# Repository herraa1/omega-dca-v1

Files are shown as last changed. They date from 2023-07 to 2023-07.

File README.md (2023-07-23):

# Omega DC Adapter (DCA) v1

DC adapter for the [Omega Home Computer](https://github.com/skiselev/omega).

## Introduction

This is a simple DC adapter for the Omega Home Computer with the following features:

* External DC input power supply
* Wide input voltage from DC +6.5V to DC +24V
* Max input current of 4A
* Power control via external SPDT switch
* Output voltages:
    * 3x independent regulated DC +5V 1.5A (max 3A)
    * 1x independent regulated DC +12V 700mA and -12V 150mA
* Three independent power circuits
* Common Reverse Polarity Protection (RPP), protects the Omega Home Computer from connecting a power barrel with inverted polarity
* Per circuit thermal shutdown, protects the Omega DC Adapter from damage when operating at exceedingly high temperatures
* Per circuit shortcircuit and Over Current Protection (OCP), protects the Omega Home Computer from shorts or excessive current (typ 5.5A)
* Per circuit Over Voltage Protection (OVP), protects the Omega Home Computer from excessive high voltages (typ 5.52V)
* Per circuit Under Voltage Protection (UVP), protects the Omega Home Computer from excessive low voltages (typ ~3V)

## Rationale

When I upgraded my Omega Home Computer with an audio amplifier board and a floppy drive I detected that, no matter how good was the power supply used, the Omega Home Computer suffered sudden resets due to power-related issues when performing some operations like, for example:
* turning on the audio amplifier while the Omega Home Computer was turned on
* increasing the audio amplifier volume up beyond a certain limit when playing compute intensive games
* inserting a floppy disk

My Omega Home Computer was using the [dc-adapter 1.6b](https://msxmakers.design.blog/proyectos/omega-home-computer/mini-fuente-dc-dc/) from [msxmakers!](https://msxmakers.design.blog/) with an external 5V power supply.

I measured the peak power consumption of the Omega Home Computer at about 1.7A with the audio amplifier on and the floppy drive spinning.

I checked several +5V power supplies with no success:
* LJH074-050030W 5V 3A (the one I purchased with the Omega Home Computer kit)
* YU0508 5V 8A (another "white brand" PSU)
* KORAD KA3005P 30V 5A (my lab bench programmable power supply...)

I used an electronic load tester (DL24 150W) and a separate multimeter (VC99) to check the actual voltage of the power supplies under load (at the power supply connector end):
* LJH074-050030W 5V 3A -> dropped to 4.9V with a 2A load and 4.6V with a 3A load
* YU0508 5V 8A -> kept a steady 5.0V with a 3A load, although it went down to 4.7V when pushing it to 6A
* KORAD KA3005P 30V 5A -> dropped to 4.8V at 5V constant voltage with a 2A load, and to 4.7V with a 3A load (required adjusting voltage to 5.3V to get 5.0V at 3A load)

So according to those load tests and the observed peak power consumption, at least the 5V 8A power supply should be capable of powering the Omega Home Computer and its upgrades without issues.
But it was not the case.

So I assumed the specific power demands of the audio amplifier and the floppy drive were causing the problems (undervoltage?) on the power rail of the Omega Home Computer.
I decided to test if the problem went away by using a separate power supply for the audio amplifier/floppy and the Omega Home Computer. I connected two 5V power supplies with a common ground, one power supply to the Omega and the other to the audio amplifier board and floppy. And voilà, no more resets.

So in the end, I decided to design a small power adapter board to provide separate power circuits to the Omega Home Computer, the audio amplifier and video converter, and the floppy drive, and while at it, added several protections just in case something went wrong with the components.

As there are lots of cheap ready to use mini boards providing part of the requirements needed, I just built a "franken-board" cannibalizing other boards to achieve the final goal.
The Omega DC Adapter was born.

## Overview

The Omega DC Adapter is a small power adapter board to provide protected and regulated power to the Omega Home Computer.
It supports the connection of an external DC power supply and a power switch to control power to the computer.

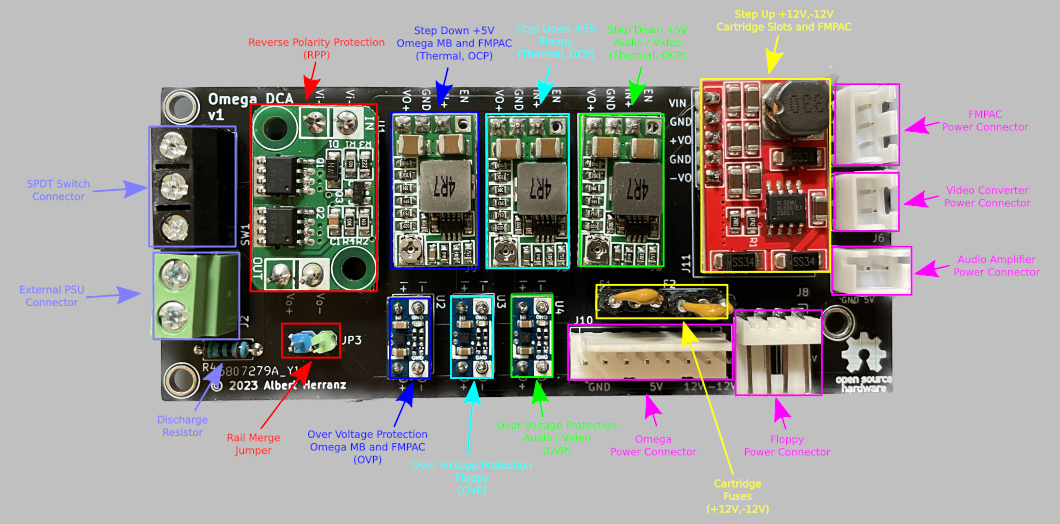
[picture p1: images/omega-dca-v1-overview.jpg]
DCA Overview


The Omega DC Adapter provides 3 independent power circuits:
* circuit #1 provides power to the Omega Home Computer motherboard and FMPAC (+5V, +12V and -12V) using conectors J10 and J12
* circuit #2 provides power to the external floppy drive (+5V) using connector J8
* circuit #3 provides power to the audio amplifier (+5V) using connector J6 and to the video converter (+5V) using connector J7

## Board

The Omega DC Adapter PCB is a 2-layer design that glues a bunch of ready-to-use mini boards:
* An ideal diode board at U1 to provide Reverse Polarity Protection, i.e. to avoid damage to the Omega Home Computer if a power supply with an incorrect polarity is connected
* Three step down mini boards with thermal shutdown and over current protection at J9, J5 and J3 to provide +5V to the three separate power circuits
* Three over voltage protection mini boards at U2, U3 and U4 to protect the three separate power circuits from overvoltages
* One step up board at J11 to provide +12V and -12V from the 5V output of J9 to feed pins 48 and 50 of the cartridge slots and the FMPAC extension

There are aswell:
* two Positive Temperature Coeficient (PTC) resettable fuses to limit the amount of current delivered to the cartridge slots, as indicated by the [MSX Cartridge Slot](https://www.msx.org/wiki/MSX_Cartridge_slot) specification
* a discharge resistor
* all the necessary connectors

The mini boards are soldered directly to the Omega DC Adapter PCB using pin headers.

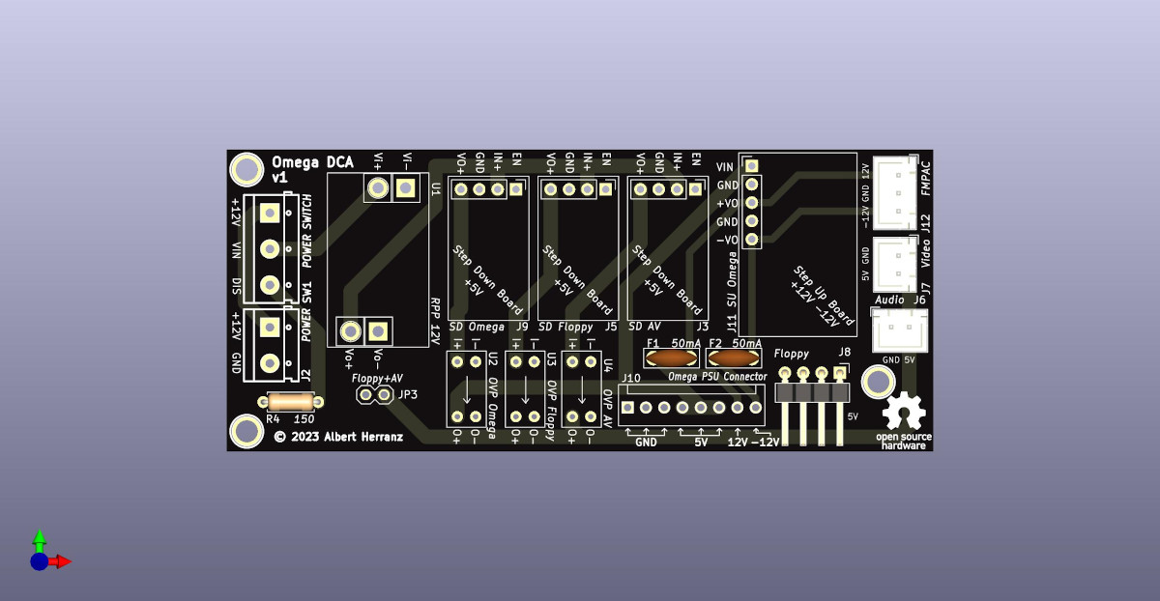
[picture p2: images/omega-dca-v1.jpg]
DCA Board


### Jumpers

Power circuits #2 and #3 can be merged if desired by populating only J5 and U3 (or J3 and U4) and closing the jumper JP3.
Otherwise, jumper JP3 should always be open.

### Connectors

#### Input Connectors

* J2 2-pin block connector, connects to external DC power supply
* SW1 3-pin block connector, connects to the SPDT power switch in the Omega Home Computer [case](https://github.com/herraa1/omega-case-x3l-v1)

#### Output Connectors

* J10, 8-pin KF2510 power connector (+5V, +12V, -12V, GND), connects to the Omega Home Computer motherboard J10 POWER connector
* J8, 4-pin Berg floppy power connector (+5V, GND), connects to the floppy drive power connector (optional)
* J6, 2-pin XH2.54 audio power connector (+5V, GND), connects to the audio amplifier power connector (optional)
* J7, 2-pin XH2.54 video power connector (+5V, GND), connects to the video converter power connector (optional)
* J12, 3-pin XH2.54 FMPAC power connector (+12V, -12V, GND), connects to the FMPAC board power connector (optional)

## Mini boards

It is recommended to always test all the boards before assembling them to verify that they behave as per their specifications.

### [Ideal Diode Board (U1)](https://www.aliexpress.com/item/1005004921885625.html)

This board provides the reverse polarity protection for the Omega DC Adapter and is based on the 4435 P-MOSFET.

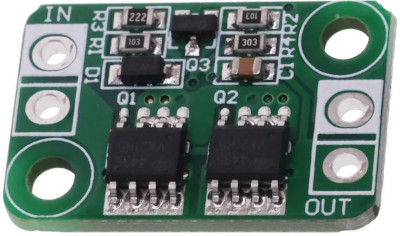
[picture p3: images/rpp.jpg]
RPP


It can work up to 30V 4A and adds minimal voltage drop due to its very low RDS(on) of 20mOhm.
The board works at the external power supply voltage, which must be between +6.5V and +24V as per the Omega DC Adapter design specifications, thus the voltage drop is unimportant in this case.

### [Step Down Boards (J9, J5, J3)](https://www.aliexpress.com/item/1005001608750898.html)

The mini step-down boards are based on the MP2315 high efficient synchronous step down switch mode converter.

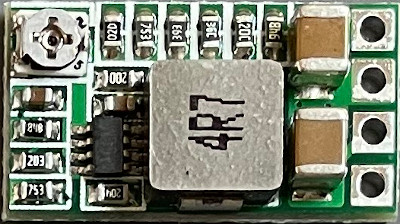
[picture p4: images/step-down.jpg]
step-down


This integrated circuit provides thermal shutdown at 150C and has a per-cycle current limit protection, which limits current to a 5.5A typically.
The mini step-down board supports input voltages from 4.5V to 24V, but for the Omega DC Adapter only 6.5V to 24V are supported because of the 5V output required.
Maximum efficiency is around 97% when a 6.5V input voltage is used. When using a 12V input voltage efficiency stays around 94%.
The board can sustain a 2.1A load, with peaks of 3A.

Two different options are available to configure the board for 5V output:
* Option #1: Severing the ADJ trace with a cutter and shorting the 5V pad with a solder blob (you may need a magnifying glass or a soldering microscope to cut the ADJ trace)
* Option #2: Using a screw driver to adjust the trimpot to the desired 5V voltage (or even a little bit more, up to 5.3V)

Option 1 will provide the native 5V voltage of the board, which may be around 5V with an error margin (it could be 4.9V, 5.0V or 5.1V if the board is ok).

Option 2 will configure the board with the selected voltage, which may be difficult to achieve due to the margin of the trimpot. Also, touching the trimpot accidentally can change the output voltage of the board to an undesired voltage (this could be specially dangerous in the 5.4V to 5.5V range, as the over voltage protection won't provide protection there).

It is recommended therefore to use Option #1 with a board that provides 5.0V or 5.1V.

### [Over Voltage Protection Boards (U2, U3, U4)](https://www.aliexpress.com/item/1005001855053619.html)

Over voltage protection is achieved by a dedicated mini board (really mini!) using an unknown IC with SMD marking 905HM.

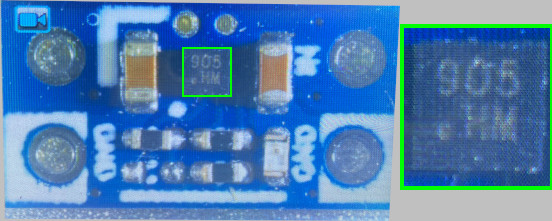
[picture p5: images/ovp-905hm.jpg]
OVP_905HM


The board cuts power and turns a red led on when more than 5.5V are detected on the input side of the board. It cuts power too when less than ~3V are detected.
The over voltage protection board supports input voltages up to 30V, so it is on the safe side even if the step down board (which sits before it) causes a short.
The board can sustain a 2.5A load, with peaks of 5A, so it is again within the 2.1A load and 3A peak of the step down board.

### [Step Up Board (J11)](https://www.aliexpress.com/item/1005003879333333.html)

The Step Up board converts the 5V from the step down board at J9 into +12V and -12V, which are then used on the cartridge slot ports and the FMPAC power connector.

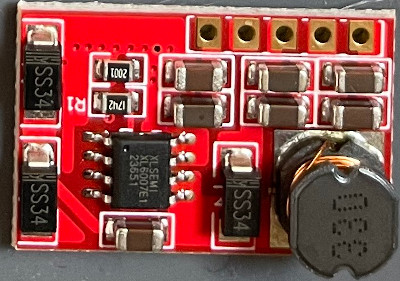
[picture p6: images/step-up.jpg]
step-up


The board supports input voltages from 3.3V to 11V, within the margins of the over voltage protection board that provides the input voltage.
On the current side, the board supports a peak 1.8A on the input and provides just a maximum of 700mA for the +12V and 150mA for the -12V.

The cartridge slot ports are protected by 50mA fuses to comply with the max 50mA for all slots MSX specification. 

## Build Instructions

Follow these [Build instructions](Build.md) in order to assemble the Omega DC Adapter board.

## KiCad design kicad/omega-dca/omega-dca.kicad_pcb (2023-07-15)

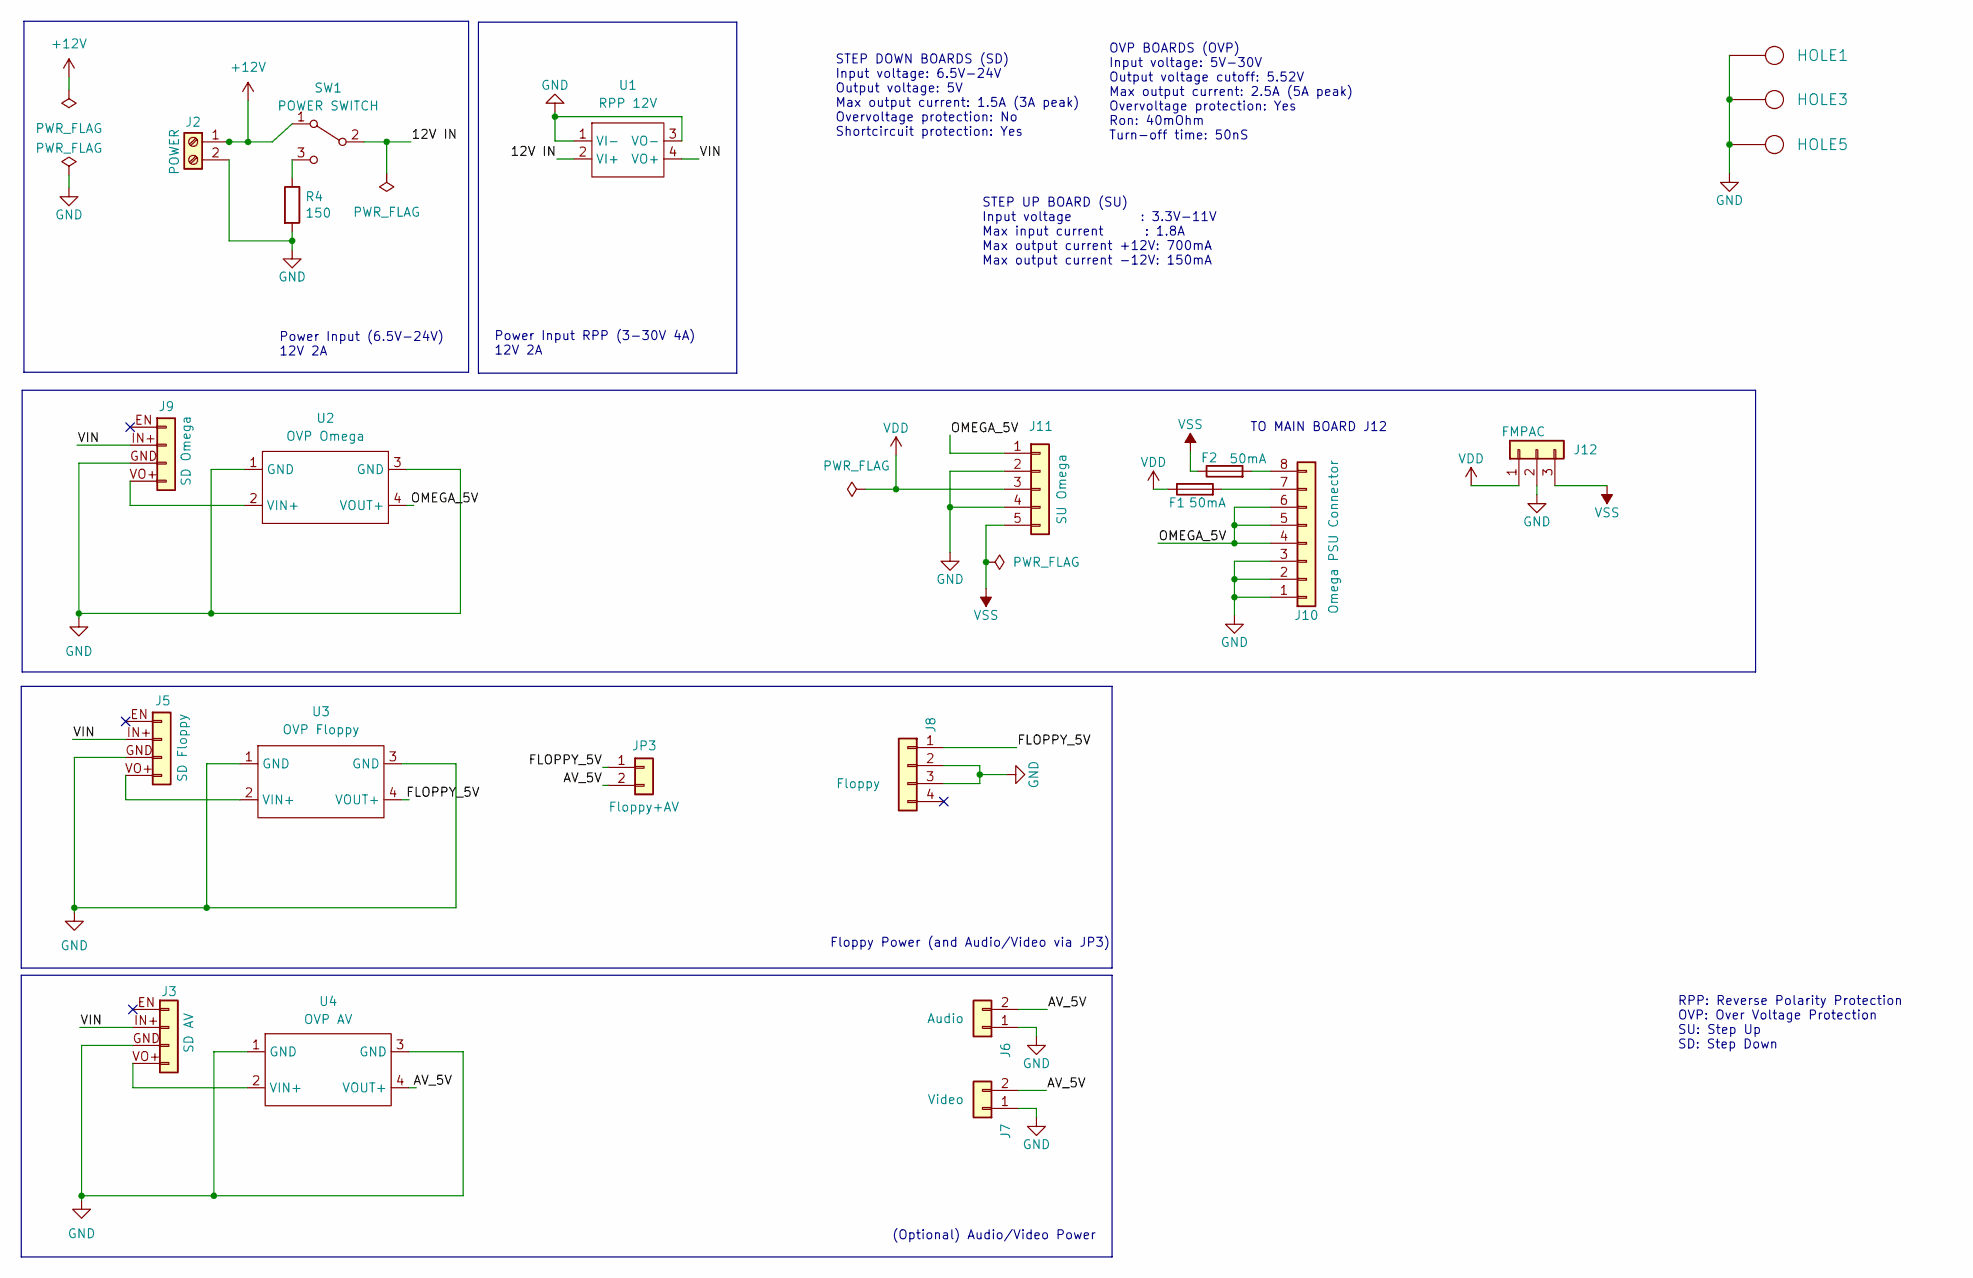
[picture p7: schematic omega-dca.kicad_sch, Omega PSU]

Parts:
F1, F2: 50mA; C_Disc_D7.5mm_W2.5mm_P5.00mm
HOLE1, HOLE3, HOLE5: HOLE; Hole_3mm
J2: POWER; Conn_Term_Block_2_5.00mm
J3: SD AV; StepDown_DC-DC_MP2315
J5: SD Floppy; StepDown_DC-DC_MP2315
J6: Audio; JST_XH_B2B-XH-A_1x02_P2.50mm_Vertical
J7: Video; JST_XH_B2B-XH-A_1x02_P2.50mm_Vertical
J8: Floppy; PinHeader_1x04_P2.54mm_Horizontal
J9: SD Omega; StepDown_DC-DC_MP2315
J10: Omega PSU Connector; Conn_Friction_Lock_8P_2.54mm
J11: SU Omega; StepUp_DC-DC_Dual
J12: FMPAC; JST_XH_B3B-XH-A_1x03_P2.50mm_Vertical
JP3: Floppy+AV; Conn_Pin_Header_2x1_2.54mm_NoKey
R4: 150; R_Axial_DIN0207_L6.3mm_D2.5mm_P7.62mm_Horizontal
SW1: POWER SWITCH; Conn_Term_Block_3_5.00mm
U1: RPP 12V; IdealDiode_3-30V-4A
U2: OVP Omega; OVP_Module_5.5V_2.5A_30V
U3: OVP Floppy; OVP_Module_5.5V_2.5A_30V
U4: OVP AV; OVP_Module_5.5V_2.5A_30V

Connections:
+12V: J2.1, SW1.1 (A)
/12V IN: SW1.2 (B), U1.2 (VI+)
/AV_5V: J6.2, J7.2, JP3.2, U4.4 (VOUT+)
/FLOPPY_5V: J8.1, JP3.1, U3.4 (VOUT+)
/OMEGA_5V: J10.4, J10.5, J10.6, J11.1, U2.4 (VOUT+)
/VIN: J3.IN+, J5.IN+, J9.IN+, U1.4 (VO+)
GND: HOLE1.1, HOLE3.1, HOLE5.1, J2.2, J3.GND, J5.GND, J6.1, J7.1, J8.2, J8.3, J9.GND, J10.1, J10.2, J10.3, J11.2, J11.4, J12.2, R4.2, U1.1 (VI-), U1.3 (VO-), U2.1 (GND), U2.3 (GND), U3.1 (GND), U3.3 (GND), U4.1 (GND), U4.3 (GND)
unnamed: F1.2, J10.7
unnamed: F2.2, J10.8
unnamed: J3.VO+, U4.2 (VIN+)
unnamed: J5.VO+, U3.2 (VIN+)
unnamed: J9.VO+, U2.2 (VIN+)
unnamed: R4.1, SW1.3 (C)
VDD: F1.1, J11.3, J12.1
VSS: F2.1, J11.5, J12.3

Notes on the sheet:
Power Input (6.5V-24V) 12V 2A
TO MAIN BOARD J12
STEP UP BOARD (SU) Input voltage : 3.3V-11V Max input current : 1.8A Max output current +12V: 700mA Max output current -12V: 150mA
RPP: Reverse Polarity Protection OVP: Over Voltage Protection SU: Step Up SD: Step Down
Power Input RPP (3-30V 4A) 12V 2A
(Optional) Audio/Video Power
STEP DOWN BOARDS (SD) Input voltage: 6.5V-24V Output voltage: 5V Max output current: 1.5A (3A peak) Overvoltage protection: No Shortcircuit protection: Yes
OVP BOARDS (OVP) Input voltage: 5V-30V Output voltage cutoff: 5.52V Max output current: 2.5A (5A peak) Overvoltage protection: Yes Ron: 40mOhm Turn-off time: 50nS
Floppy Power (and Audio/Video via JP3)

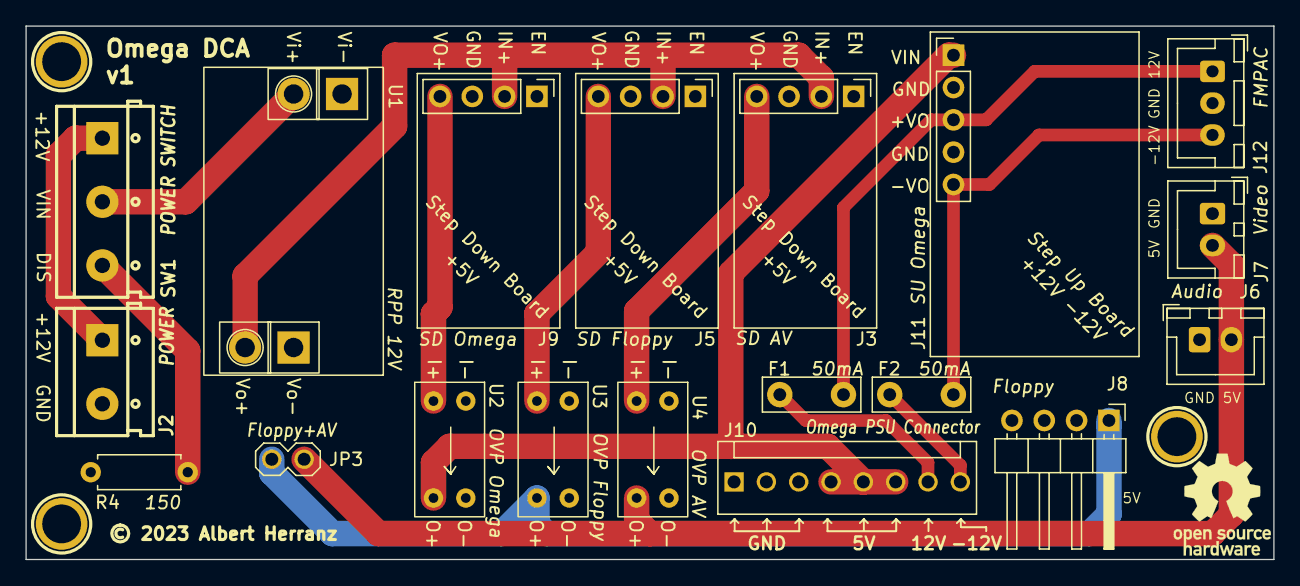
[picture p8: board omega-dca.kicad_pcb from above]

Board: 2 copper layers, 98.0 x 41.9 mm, 22 parts (0 on the bottom side), 15 nets.

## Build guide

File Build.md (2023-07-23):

# Build Instructions

This document describes how to assemble an Omega DC Adapter.

## Bill Of Materials (BOM)

| **ref** | **item** | **image** | **req_pcs** | **aliexpress_item** | **pcs_per_item** | **req_items** | **option** | **link** |
| --- | --- | --- | --- | --- | --- | --- | --- | --- |
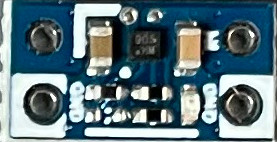
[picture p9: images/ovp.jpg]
| U2, U3, U4 | OVP mini board | [](images/ovp.jpg) | 3 | WeAct Over-Voltage Protection Module OVP 5.5V 2.5A 30V Power-protection Mini | 1 | 3 | | [aliexpress](https://www.aliexpress.com/item/1005001855053619.html) |
| J11 | Step Up +12V -12V board | [](images/step-up.jpg) | 1 | A08 DC-DC Boost Power Supply Module 5V 9V 12V 15V 24V Power Supply Module Ultra Small Step Up Circuit Board | 1 | 1 | 12V | [aliexpress](https://www.aliexpress.com/item/1005003879333333.html) |
| U1 | Ideal Diode RPP | [](images/rpp.jpg) | 1 | Ideal Diode Module Battery Charging Charger Anti Reverse Connection Power Protection Board Module 4A Common Ground DC3-30V | 1 | 1 | | [aliexpress](https://www.aliexpress.com/item/1005004921885625.html) |
| J9, J5, J3 | Step Down 5V mini board | [](images/step-down-front-trimpot.jpg) | 3 | Mini DC-DC 12-24V To 5V 3A Step Down Power Supply Module Buck Converter Adjustable Efficiency 97.5% | 1 | 3 | | [aliexpress](https://www.aliexpress.com/item/1005001608750898.html) |
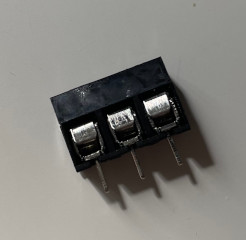
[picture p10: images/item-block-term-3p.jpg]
| SW1 | 3P block terminal | [](images/item-block-term-3p.jpg) | 1 | 10 PCS KF301-5.0-3P Pitch 5.0mm KF301-3P Straight Pin PCB 2 Pin 3 Pin Screw Terminal Block Connector | 10 | 1 | Black | [aliexpress](https://www.aliexpress.com/item/32842003333.html) |
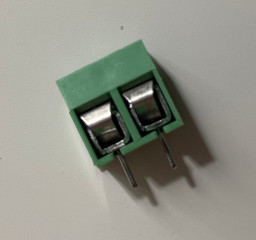
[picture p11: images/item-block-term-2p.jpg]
| J2 | 2P block terminal | [](images/item-block-term-2p.jpg) | 1 | 10 PCS KF301-5.0-2P Pitch 5.0mm KF301-2P Straight Pin PCB 2 Pin 3 Pin Screw Terminal Block Connector | 10 | 1 | Green | [aliexpress](https://www.aliexpress.com/item/32842015184.html) |
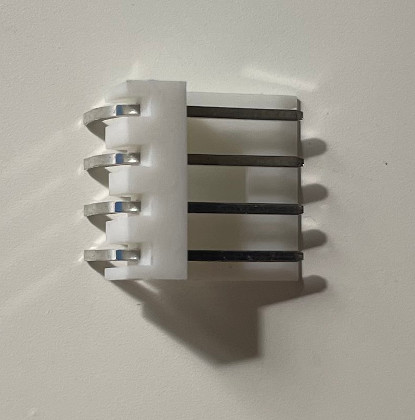
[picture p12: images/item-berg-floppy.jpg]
| J8 | Berg Connector Right Angle | [](images/item-berg-floppy.jpg) | 1 | 10pcs Mini 4P Connector Floppy Power Supply Jack 2.54mm Pitch Housing Straight Right Angle Socket Housing Terminals | 10 | 1 | Right Angle Flat | [aliexpress](https://www.aliexpress.com/item/1005004647707706.html) |
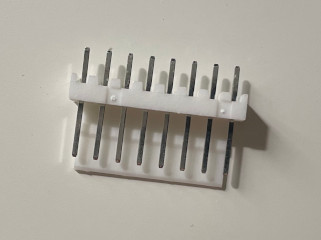
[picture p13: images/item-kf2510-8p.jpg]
| J10 | 8P KF2510 Male Straight | [](images/item-kf2510-8p.jpg) | 1 | 20 Sets KF2510 Connector Kits 2.54mm Pitch 2/3/4/5/6/7/8/9/10P Straigh Pin Header+Housing+Crimp KF-2510 | 20 | 1 | 8P | [aliexpress](https://www.aliexpress.com/item/4000229636156.html) |
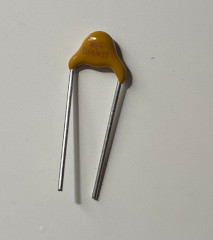
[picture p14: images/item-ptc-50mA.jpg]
| F1, F2 | 50mA PTC fuse | [](images/item-ptc-50mA.jpg) | 2 | JK16 16V Resettable Fuse WDS16 PPTC RGEF 0.5A 0.75A 1.1A 1.35A 1.5A 1.6A 1.85A 2A 2.5A 3A 4A 5A 6A 10A 11A 12A 13A 14A 15A | 10 | 1 | 0.05A | [aliexpress](https://www.aliexpress.com/item/32870368102.html) |
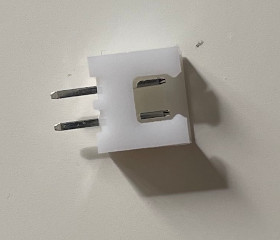
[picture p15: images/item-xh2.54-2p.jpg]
| J6, J7 | 2P XH2.54 male straight header | [](images/item-xh2.54-2p.jpg) | 2 | 230pcs XH2.54 PH2.0 2p 3p 4p 5 pin 2.54mm 2.0mm Pitch Terminal Kit Housing Pin Header JST Connector Wire Connectors Adaptor | 230 | 1 | XH2.54-1BOX | [aliexpress](https://www.aliexpress.com/item/33001807525.html) |
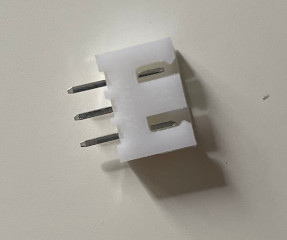
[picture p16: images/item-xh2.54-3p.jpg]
| J12 | 3P XH2.54 male straight header | [](images/item-xh2.54-3p.jpg) | 1 | 230pcs XH2.54 PH2.0 2p 3p 4p 5 pin 2.54mm 2.0mm Pitch Terminal Kit Housing Pin Header JST Connector Wire Connectors Adaptor | | 0 | XH2.54-1BOX | [aliexpress](https://www.aliexpress.com/item/33001807525.html) |
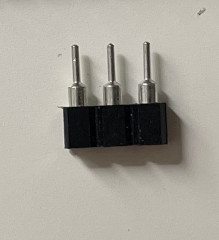
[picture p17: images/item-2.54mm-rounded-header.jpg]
| F1, F2 | 2.54mm pitch round hole female header | [](images/item-2.54mm-rounded-header.jpg) | 1 | 5 Pcs Round Hole Pin Header 2.0MM/2.54MM Pitch Row Female/Male, Single Row 1x40P Row 2x40P Double Row Pin Round Pin Gold Plated | 5 | 1 | 2.54 1row femal sliv | [aliexpress](https://www.aliexpress.com/item/4001122376295.html) |
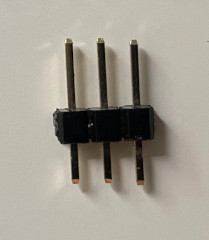
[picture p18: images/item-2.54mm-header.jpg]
| JP3 | 2.54mm pitch male pin header | [](images/item-2.54mm-header.jpg) | 1 | Hot Sale 40Pin 1x40 Single Row Male 2.54 Breakable Pin Header Connector Strip Colorful pin For Arduino Diy Kit | 10 | 1 | 5 color | [aliexpress](https://www.aliexpress.com/item/1005004301488282.html) |

## Step Down 5V Mini Boards Preparation

### Output voltage configuration

Two different options are available to configure the step down mini board for 5V output:
* Option #1: Severing the ADJ trace with a cutter and shorting the 5V pad with a solder blob (you may need a magnifying glass or a soldering microscope to properly cut the ADJ trace!)
* Option #2: Using a screw driver to adjust the trimpot to the desired 5V voltage

#### Preparation option #1

In order to configure the +5V output voltage (or any other fixed voltage) you need to first cut the ADJ trace on the bottom side of the step down mini board.

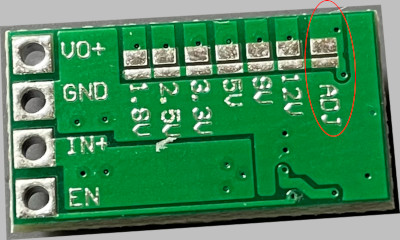
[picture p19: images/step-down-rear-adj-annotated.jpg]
step-down-rear-adj-annotated

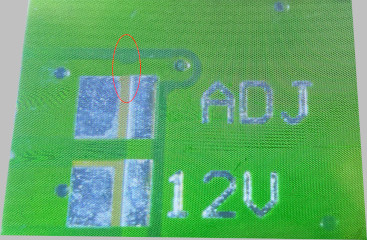
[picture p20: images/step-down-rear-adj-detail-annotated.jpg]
step-down-rear-adj-detail-annotated

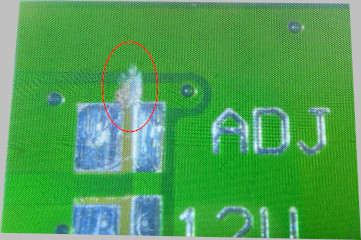
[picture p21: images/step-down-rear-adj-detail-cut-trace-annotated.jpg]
step-down-rear-adj-detail-cut-trace-annotated


Then you need to join the 5V pad with a blob of solder.

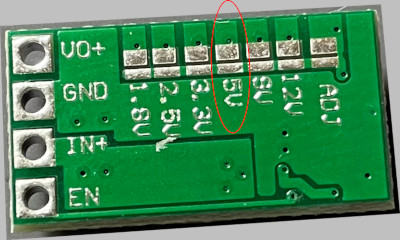
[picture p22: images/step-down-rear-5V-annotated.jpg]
step-down-rear-5V-annotated

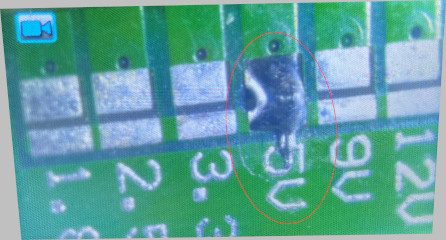
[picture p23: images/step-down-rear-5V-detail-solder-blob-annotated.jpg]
step-down-rear-5V-detail-solder-blob-annotated


Once the step down mini board is prepared you can use a multimeter to test the voltage between GND and VO+ while applying 12V (or any voltage between 6.5V and 24V) to IN+ using an external power supply, and connecting GND to the power supply ground reference.

The output voltage should read +5V with a +/- 0.1V margin error.

#### Preparation option #2

The step down boards come from factory in the "manual adjustment mode" or ADJ. In this mode you use the included trimpot to adjust the output voltage of the step down mini board.

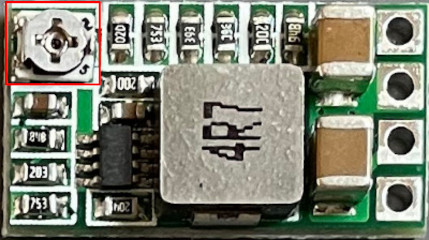
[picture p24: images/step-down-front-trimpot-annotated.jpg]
step-down-front-trimpot-annotated


In order to adjust the output voltage to +5V (or any value between +5.0V and +5.2V) you need to apply 12V (or any voltage between 6.5V and 24V) to IN+ using an external power supply, and connect GND to the power supply ground reference. Then, with the help of a multimeter connected between GND and VO+, you adjust the trimpot with a screwdriver until the output voltage gets to the desired value.

Keep in mind that the trimpot is very sensitive and a minor trimpot adjustment can cause a big change in the output voltage.

### Installation of pin headers in mini boards

The step down mini boards should be ideally installed using soldered 2.54mm pitch male pin headers.

The short leg of the pin headers should be inserted via the bottom side of the mini boards, and soldered from the top side of the mini boards. This will place the "bandolier" (insulator plastic of the pin header) on the bottom side of the mini board to separate the mini board from the Omega DC Adapter PCB.

#### Pin header preparations

All required pin headers are single row male pin headers.

| board | headers per board |
|---|---|
| step down 5V mini board | 1x 3p or 4p [^1]  |
| ideal diode RPP mini board | 4x 1p |
| step up +12V/-12V mini board | 1x 5p |
| OVP mini board | 2x 2p |

[^1]: The EN pin of the step down 5V mini boards is not used (the board is ON when the EN pin is floating) so a 3p male header is enough, but you may prefer to solder a 4p header.

#### Soldering pin headers to mini boards

You can use a breadboard to help you solder the pin headers to their respective mini boards, as explained for example in the following video (for the [Raspberry Pi Pico](https://en.wikipedia.org/wiki/Raspberry_Pi#Raspberry_Pi_Pico)).

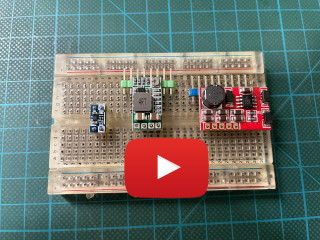
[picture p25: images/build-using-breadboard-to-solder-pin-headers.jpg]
soldering header pins (https://youtube.com/shorts/u3A2UhlUC2w?feature=share)


Alternatively, you can use the Omega DC Adapter bare PCB as a helping tool for aligning and soldering the pin headers to the mini boards.

First, temporarily install spacers on the bottom of the PCB using the three existing PCB holes to make some room for the pin headers (otherwise the pin headers will pop out when putting the PCB on a flat surface).

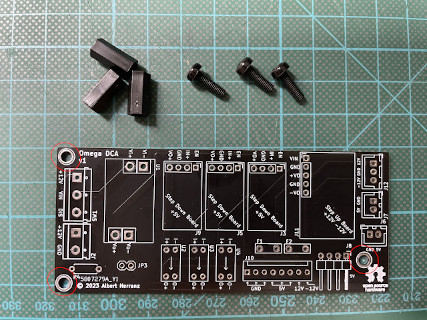
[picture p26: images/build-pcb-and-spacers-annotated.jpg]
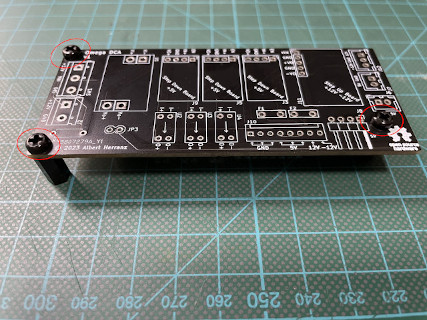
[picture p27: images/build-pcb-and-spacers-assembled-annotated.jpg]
 

Second, place the pin headers on their respective footprints through the front side of the PCB, making sure that the short leg of the pin header faces up, the "bandolier" sits on the front side of the PCB, and the large leg faces down and gets inserted into the footprint on the PCB.

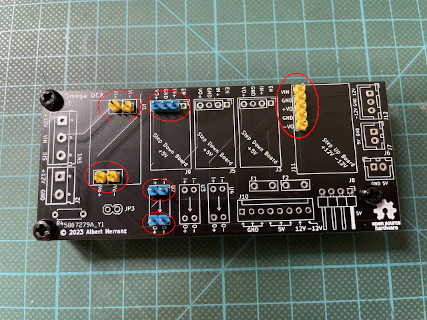
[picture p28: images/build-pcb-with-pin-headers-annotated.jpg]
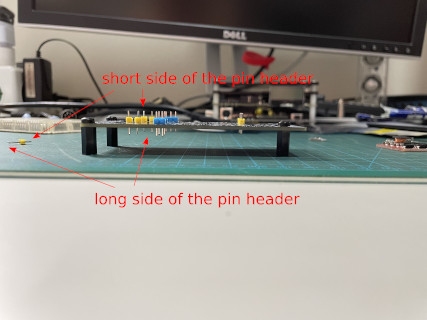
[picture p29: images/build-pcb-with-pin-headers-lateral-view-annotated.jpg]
 

Next, lay down the mini boards on top of the installed headers and use some spare headers to level up those boards that only have pins on one side. Then secure the boards with some Blu-Tack blobs to prevent unwanted movements while soldering the pin headers.

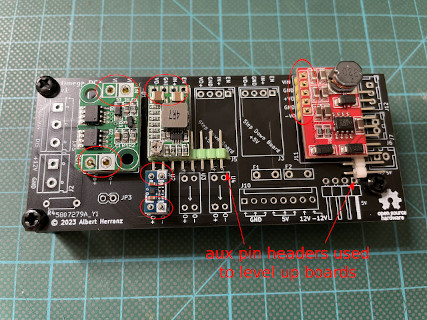
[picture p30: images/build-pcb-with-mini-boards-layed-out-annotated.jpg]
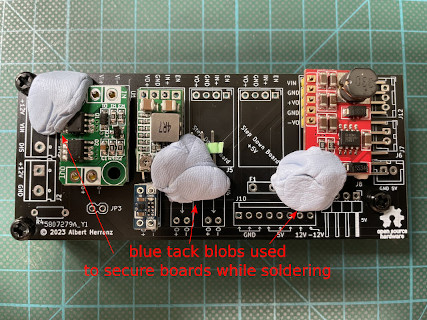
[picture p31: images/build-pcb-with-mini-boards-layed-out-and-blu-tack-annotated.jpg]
 

Now you can solder the pin headers to the mini boards. Do not solder yet the pin headers to the Omega DC Adapter PCB, this will be done in a later step.

You will need to repeat this process twice again to complete the preparation of the three step down mini boards and the three OVP mini boards.

Once finished, you can remove the temporary spacers from the Omega DC Adapter.

### Soldering the board components

Once the mini boards have been prepared and populated with soldered headers, you can start assembling all the Omega DC Adapter PCB components.

Remember to use spare headers when needed to level up those mini boards with pin headers only on one side, and use Blu-Tack blobs and/or blue masking tape to secure the mini boards to the Omega DC Adapter PCB on the top side while soldering on the bottom side. Note that Blu-Tack can get softer when heated during soldering, so let it cool down to ease removal. If Blu-Tack gets stuck to the PCB or components, add additional Blu-Tack to remove it easily.

1. First, start by soldering the three OVP mini boards (U2, U3 and U4) and the Berg floppy connector (J8) to the bottom side of the Omega DC Adapter PCB.

   You can solder the 50mA PTC fuses (F1 and F2) directly on the PCB or alternatively solder rounded pin headers to enable insertion and removal of PTC fuses (as seen in the next animated picture).

2. Continue by soldering the Ideal Diode RPP mini board (U1) to the bottom side of the Omega DC Adapter PCB using four soldering points.

3. Then move to soldering the three step down 5V mini boards (J9, J5 and J3) to the bottom side of the Omega DC Adapter PCB, each one with three soldering points.

4. Now it's time to solder the step up +12V/-12V mini board (J11), again by carrying five solder joints on the bottom side of the Omega DC Adapter PCB.

5. Next, proceed to solder the XH2.54 FM-PAC (J12), Video (J7) and Audio (J6) connectors, and the JP3 jumper.

6. The block terminals (J2 and SW1) can now be soldered.

7. Follow up by soldering the KF2510 8p Omega power connector (J10)

8. And finish the board assembly by soldering the discharge resitor R4 and connecting the 50mA PTC fuses using soldered round headers (if not soldered directly to the Omega DC Adapter PCB).

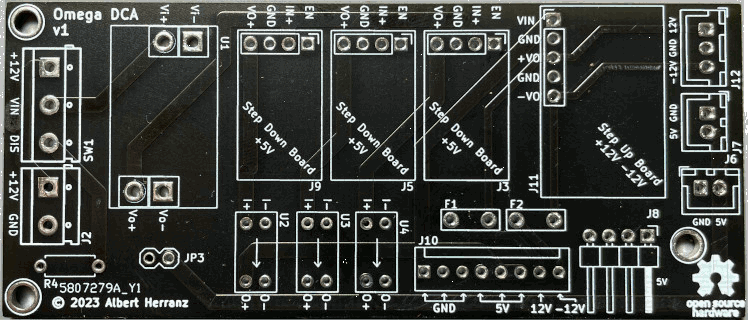
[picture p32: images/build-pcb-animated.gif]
DCA Build Sequence


### Final touches

You can shorten the pin header legs on the bottom of the Omega DC Adapter by using diagonal pliers.

### Testing the board

Before using the Omega DC Adapter to power the Omega Home Computer it is strongly recommended to verify that the correct voltages are present at the Omega DC Adapter power connectors.

For testing purposes, prepare a 12V external Power Supply Unit (PSU) and connect the VIN terminal of SW1 to the PSU cathode (positive terminal) and the GND terminal of J2 to the PSU anode (negative terminal).
Switch on the 12V external PSU and measure voltages between GND and all the specified testing points in the following diagram. You should observe the documented voltage at each testing point.

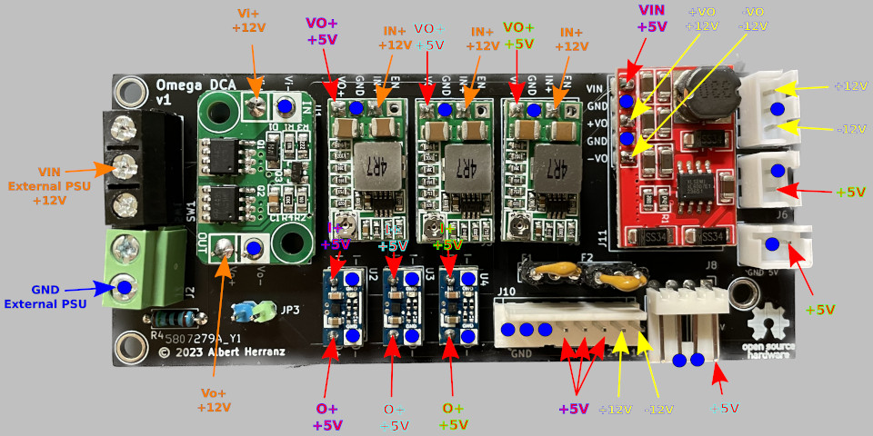
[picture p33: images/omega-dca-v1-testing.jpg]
DCA Testing


### Connecting the board

The board must be connected to an external Power Supply Unit (PSU) and a Single Pole Double Throw (SPDT) switch as described in the following diagram.

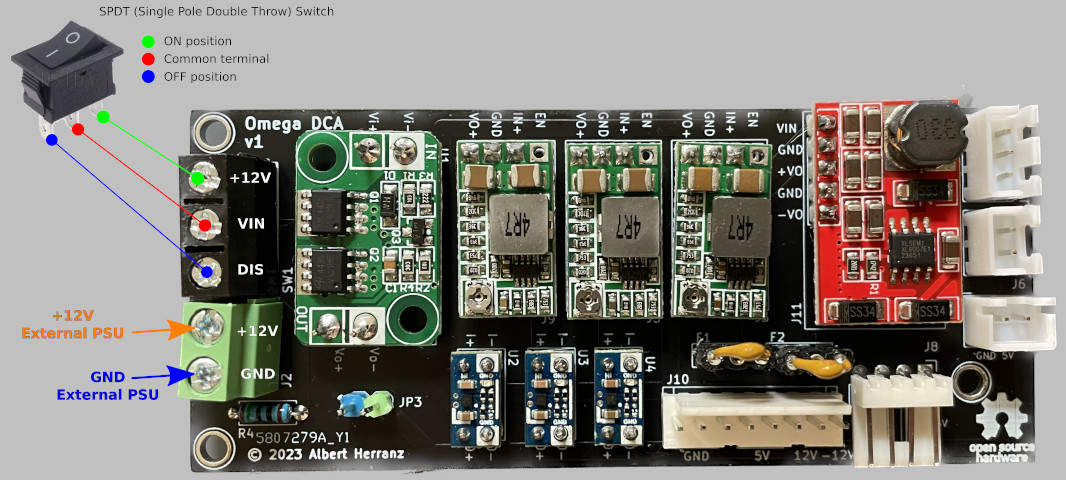
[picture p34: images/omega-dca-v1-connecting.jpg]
DCA Connecting


### Installing the board

The Omega DC Adapter can be installed in different places depending on the specific computer case used for the Omega Home Computer.

In this case, a [X3L Computer case](https://github.com/herraa1/omega-case-x3l-v1) is used and the Omega DC Adapter is installed beneath the keyboard.

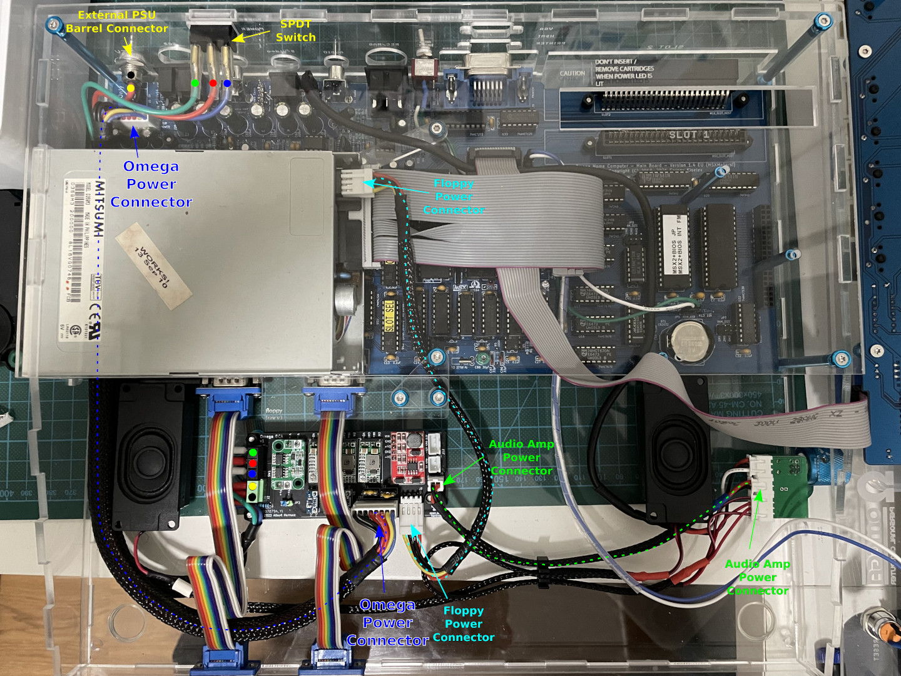
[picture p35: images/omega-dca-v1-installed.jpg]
[](images/omega-dca-v1-installed.jpg)

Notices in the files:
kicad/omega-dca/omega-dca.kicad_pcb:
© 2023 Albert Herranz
